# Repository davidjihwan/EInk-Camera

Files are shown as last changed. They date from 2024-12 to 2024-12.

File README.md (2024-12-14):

# eInk Camera
A camera that uses an eInk display, using the Adafruit Grand Central M4.
Image of the eink camera

## Summary
This project is an eInk camera. The camera takes a picture of the user when they click a button, saves it to an SD card, then flashes it onto an eInk display. 
More of the design details and process can be found in the writeup I did on [my website](https://davidjihwan.com/eInk-Camera).

## Media
Thresholding: <br />
Gif of the camera's thresholding function

Dithering (default): <br />
Gif of the camera's dithering function

The full interaction (dithering): <br />
Gif of the full camera interaction

Closeup: <br />
Gif of the full camera interaction

## Materials
- [Arduino IDE](https://www.arduino.cc/en/software)
- [Adafruit Grand Central M4 Express](http://www.adafruit.com/product/4064#tutorials)
- [Adafruit 1.54" Monochrome eInk / ePaper Display with SRAM](http://www.adafruit.com/product/4196#tutorials)
- [Adafruit EYESPI Breakout Board](http://www.adafruit.com/product/5613#tutorials)
- [EYESPI Cable - 18 Pin 100mm long Flex PCB (FPC) A-B type](https://www.adafruit.com/product/5239#tutorials)
- Micro USB cable (data)
- SD Card
- OV7670 Camera Module
- 2x: 2.2k resistors
- Breadboard
- M-F jumper wires
- M-M jumper wires
- Wires
- Pushbutton
  
Optional (for display enclosure):
- 2x: M2 screws & nuts

This project also requires soldering.

## Quick Start Guide
Download the [Arduino IDE](https://www.arduino.cc/en/software) on your computer of choice.

Camera setup:
1. Install the Adafruit OV7670 library using the Arduino Library Manager. 
2. Follow Phillip Burgess' guide "Adafruit OV7670 Camera Library For SAMD51 Processors" to modify the OV7670 camera to interface with the Grand Central: 
[https://learn.adafruit.com/adafruit-ov7670-camera-library-samd51/hardware](https://learn.adafruit.com/adafruit-ov7670-camera-library-samd51/hardware)  
Your camera should look like this after modification: <br />
<a href="url"> <br />
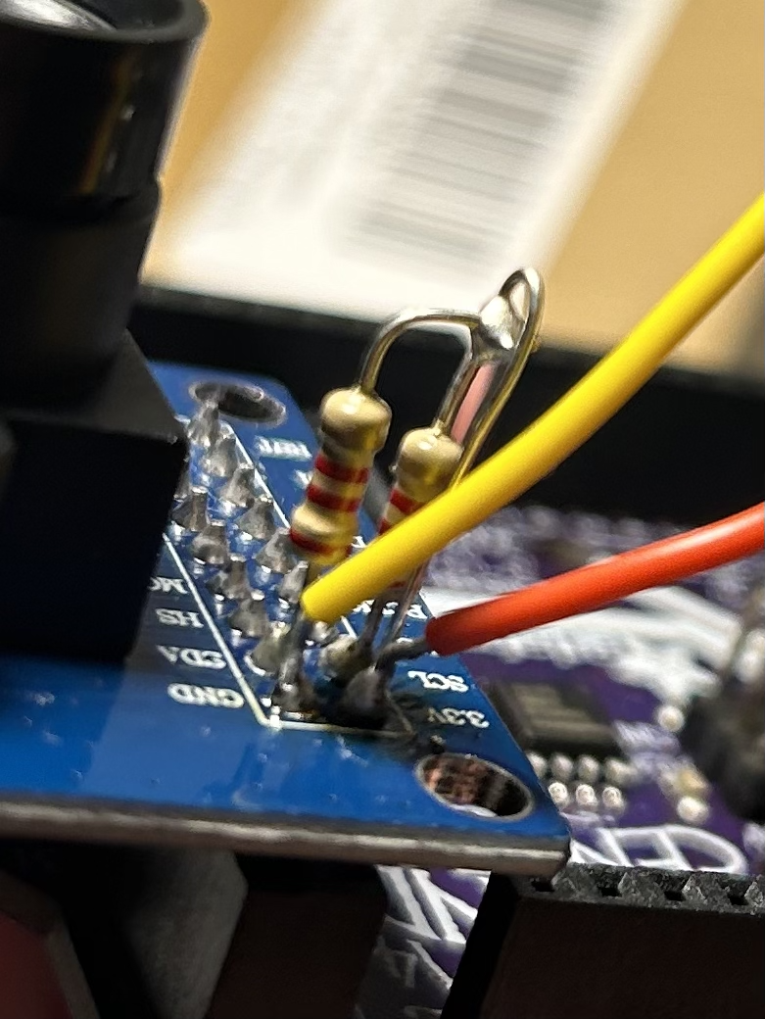
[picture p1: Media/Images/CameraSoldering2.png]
<a href="url"> <br />
Insert the camera into the Grand Central as detailed in the guide: <br />
<a href="url">
4. Ensure that the camera is working using the "selfie" example in the "Adafruit OV7670" library. You don't need the TFT screen; just remove the SD card and check the images manually. 

Eink setup:
1. Install the Adafruit EPD library using the Arduino Library Manager. 
2. Wire connections following the wiring diagram below.
3. Ensure that the eink display is working using the "ThinkInk_Mono" example in the "Adafruit EPD" library. If this isn't working, make sure to check that you are using a good data transfer micro USB cable. I ran into an issue where the subpar cable I used couldn't handle both the camera and eink display being plugged in at the same time.

Here's the wiring diagram for this project. <br />
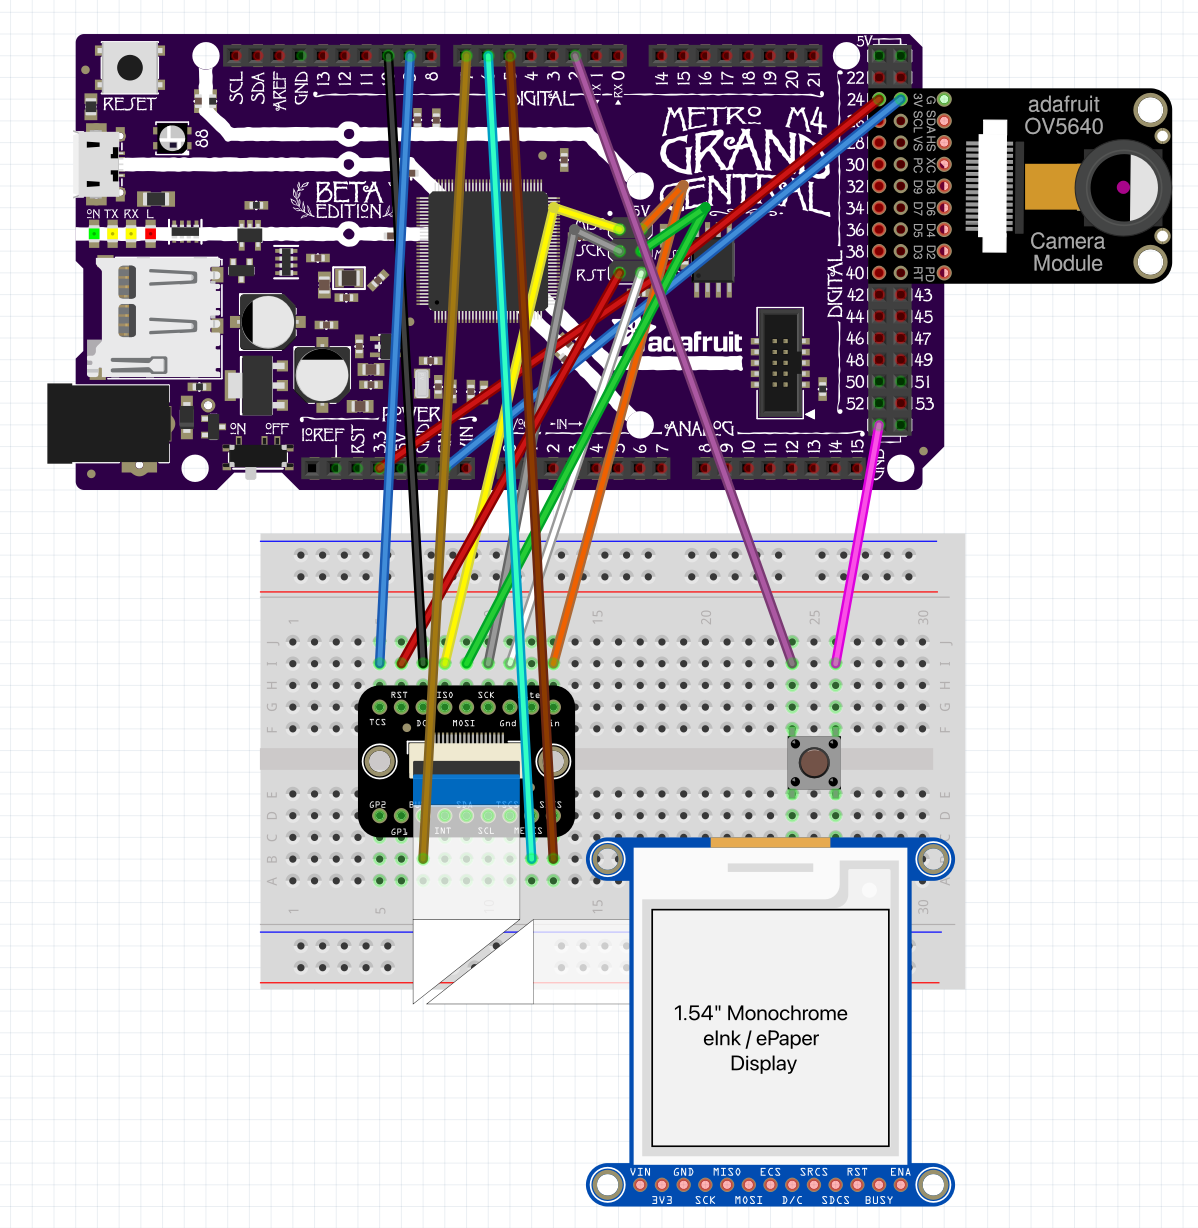
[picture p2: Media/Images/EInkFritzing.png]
<a href="url"> 

Here's what your wiring should look like:<br />
<a href="url"> <br />
<a href="url"> <br />

Project Installation and Setup:
1. Download the Arduino project file to write to serial output [here](Arduino/Eink_Camera/Eink_Camera.ino).
3. Open the project file.
4. Change your board: Tools > Boards > Adafruit SAMD Boards > Adafruit Grand Central M4
5. Change the port: Tools > Port > your-port (mac users should select “wchusb")
6. Plug the Grand Central into your computer.
7. Press the upload button (at the top left of the window) to upload your code to the board. Arduino should automatically download any missing dependencies. 
8. That's it! After you click the button, the image should be flashed onto the eink display. 

Optional Enclosure: <br />
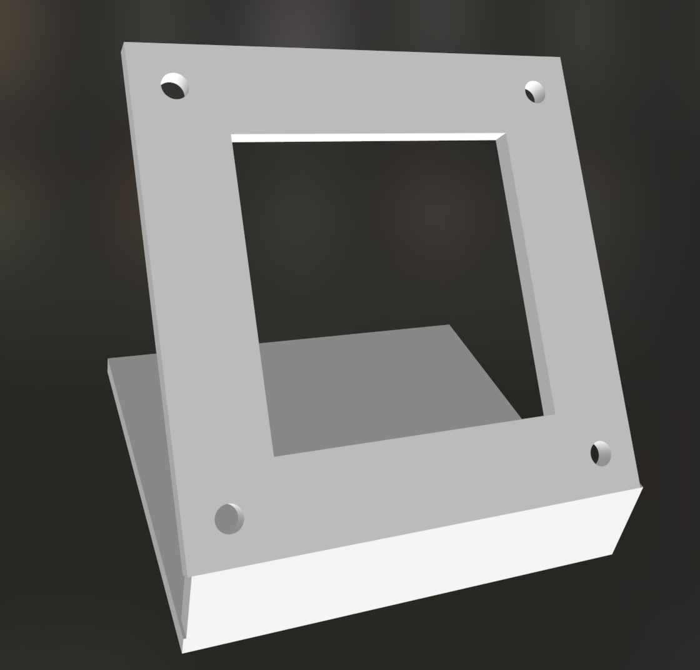
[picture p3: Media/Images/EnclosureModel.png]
<a href="url">
1. Download the file for the joystick enclosure [here](3D_Models/EInkStandScaled.stl) and print it.
2. Screw the eink display onto the back of the enclosure using M2 screws and hold it in place using the corresponding nuts.
The final enclosure looks like this: <br />
<a href="url">

I also tried making a cardboard enclosure for the camera: <br />
<a href="url">

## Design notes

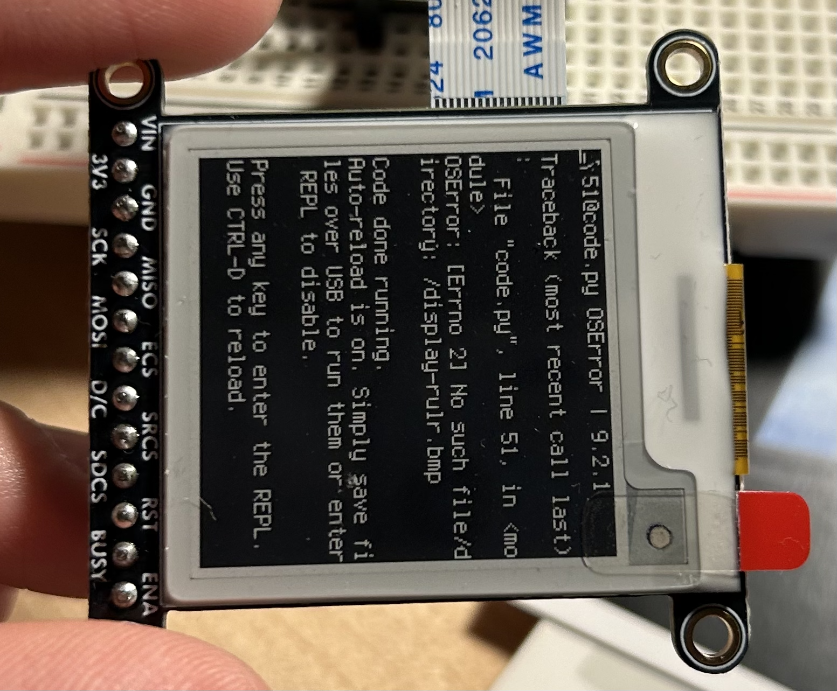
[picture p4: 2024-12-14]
Media/Images/EinkError.png

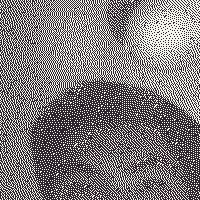
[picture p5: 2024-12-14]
Media/Images/dithered.png

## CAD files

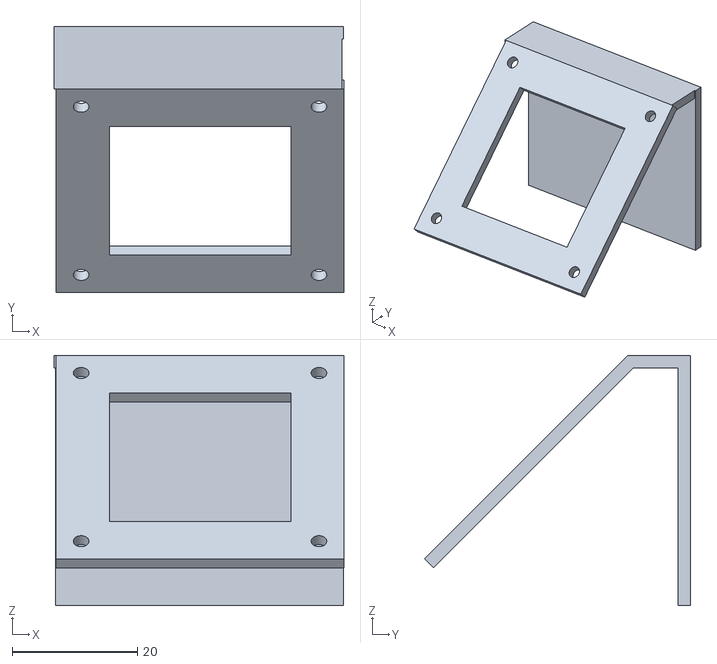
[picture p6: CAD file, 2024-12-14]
3D_Models/EInkStandScaled.stl
46.3 x 42.5 x 40.0

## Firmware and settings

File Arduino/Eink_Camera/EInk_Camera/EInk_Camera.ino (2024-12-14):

/*
Author: David Jihwan
Github: https://github.com/davidjihwan/eInk_Camera/tree/main
Website: https://davidjihwan.com/eInk-Camera

Takes a picture of the user when they click a button, saves it to an SD card, then flashes it onto an eInk display. 

HARDWARE REQUIRED:
- Adafruit Grand Central board
- OV7670 camera w/2.2K pullups to SDA+SCL
- Adafruit ThinkInk display
- SD Card

This project draws from example code written by Adafruit: 
- Examples/Adafruit ImageReader Library/ThinkInkDisplays: 
https://github.com/adafruit/Adafruit_ImageReader/blob/master/examples/ThinkInkDisplays/ThinkInkDisplays.ino
- Examples/Adafruit OV7670/selfie: 
https://github.com/adafruit/Adafruit_OV7670/blob/master/examples/selfie/selfie.ino

I also referenced Phillip Burgess' guide "Adafruit OV7670 Camera Library For SAMD51 Processors" 
in order to modify my OV7670 camera to interface with the Grand Central: 
https://learn.adafruit.com/adafruit-ov7670-camera-library-samd51/hardware  

*/

#include <Adafruit_GFX.h>             // Core graphics library
#include "Adafruit_ThinkInk.h"        // ThinkInk library
#include <Wire.h>                     // I2C comm to camera
#include "Adafruit_OV7670.h"          // Camera library
#include <SdFat.h>                    // SD card & FAT filesystem library
#include <Adafruit_SPIFlash.h>        // SPI / QSPI flash library
#include <Adafruit_ImageReader_EPD.h> // Image-reading functions

// SD CONFIG ----------------------------------------------------------
// #define SD_CS SDCARD_SS_PIN       // Grand Central onboard SD card select
#define SD_CS 5                      // SD card chip select (on ThinkInk Display)
SdFat                    SD;         // SD card filesystem
Adafruit_ImageReader_EPD reader(SD); // Image-reader object, pass in SD filesys

// CAMERA CONFIG -----------------------------------------------------------

// Set up arch and pins structures for Grand Central's SAMD51.
// PCC data pins are not configurable and do not need specifying.
OV7670_arch arch = {.timer = TCC1, .xclk_pdec = false};
OV7670_pins pins = {.enable = PIN_PCC_D8, .reset = PIN_PCC_D9,
                    .xclk = PIN_PCC_XCLK};
#define CAM_I2C  Wire1 // Second I2C bus next to PCC pins
#define CAM_SIZE OV7670_SIZE_DIV2 // QVGA (320x240 pixels)
#define CAM_MODE OV7670_COLOR_YUV // We need to process greyscale data
Adafruit_OV7670 cam(OV7670_ADDR, &pins, &CAM_I2C, &arch);

// EINK DISPLAY CONFIG -----------------------------------------------------------
#define EPD_DC      10
#define EPD_CS      9
#define EPD_BUSY    7    // can set to -1 to not use a pin (will wait a fixed delay)
#define SRAM_CS     6
#define EPD_RESET   -1   // can set to -1 and share with microcontroller Reset!
#define EPD_SPI     &SPI // primary SPI
// 1.54" Monochrome displays with 200x200 pixels and SSD1681 chipset
// ThinkInk_154_Mono_D67 display(EPD_DC, EPD_RESET, EPD_CS, SRAM_CS, EPD_BUSY, EPD_SPI);
ThinkInk_154_Mono_D67 display(EPD_DC, EPD_RESET, EPD_CS, SRAM_CS, EPD_BUSY);

// BUTTON CONFIG -----------------------------------------------------------
#define BUTTON_PIN 2

// SETUP - RUNS ONCE ON STARTUP --------------------------------------------
void setup() {
  pinMode(13, OUTPUT);  // Onboard red LED
  pinMode(BUTTON_PIN, INPUT_PULLUP); // Use internal pullup resistor
  Serial.begin(9600);
  Serial.println("Began!");

  // Initialize SD & file system
  if(!SD.begin(SD_CS, SD_SCK_MHZ(10))) { // Breakouts require 10 MHz limit due to longer wires
    Serial.println(F("SD begin() failed"));
    for(;;); // Fatal error, do not continue
  }

  // Once started, the camera continually fills a frame buffer using DMA.
  OV7670_status status = cam.begin(CAM_MODE, CAM_SIZE, 30.0, 320 * 240 * 2);
  if (status != OV7670_STATUS_OK) {
    Serial.println("Camera begin() fail");
    for(;;); // Fatal error, do not continue
  }
  // We don't want DMA into the camera buffer for this project, as
  // the camera should only be active when the button is pressed.
  cam.suspend();
  display.begin();
  display.setRotation(2);
  display.clearBuffer();
}

// MAIN LOOP - RUNS REPEATEDLY UNTIL RESET OR POWER OFF --------------------
void loop() {
  delay(40);  // Check button press every 40ms
  int buttonState = digitalRead(BUTTON_PIN);
  if(!buttonState) {
    digitalWrite(13, HIGH);   // turn the LED on

    // ********** HANDLE CAMERA **********
    Serial.println("Taking picture.");
    char filename[50];
    sprintf(filename, "selfie.bmp");
    // delay(500);      // Small delay for user to get ready
    cam.capture();      // Manual (non-DMA) capture
    bool *correspondence = (bool *)malloc(cam.height() * cam.width() * sizeof(bool));   // Remember to free!!!
    if (correspondence == NULL) {
      Serial.println("Correspondence malloc error");
      for(;;); // Fatal error, do not continue
    }
    dither(cam.getBuffer(), cam.width(), cam.height(), correspondence);
    write_bmp_correspond(filename, correspondence, cam.width(), cam.height(), 
                       display.height(), display.width());
    free(correspondence);

    // ********** HANDLE SCREEN **********
    // Load full-screen BMP file 'selfie.bmp' at position (0,0) (top left).
    // The 'reader' object performs this, with 'epd' as an argument.
    Serial.print(F("Loading bmp to canvas..."));
    ImageReturnCode stat; // Status from image-reading functions
    stat = reader.drawBMP((char *)"selfie.bmp", display, 0, 0);
    reader.printStatus(stat); // How'd we do?
    display.display();  
    display.clearBuffer();
    digitalWrite(13, LOW);  // Turn the LED off
    delay(5000);            // Adafruit recommends a max refresh rate of 180 seconds. If you care
                            // about the longevity of your screen, increase the delay. 
  }
}

// Perform Floyd-Steinberg dithering on the image and fill in the correspondence array with the 
// results (0: black, 1: white). 
// This changes the values in the camera buffer in order to avoid using more RAM. Use with caution.
void dither(uint16_t *addr, uint16_t width, uint16_t height, bool *correspondence){
  // Serial.println("Dithering.");
  if(CAM_MODE != OV7670_COLOR_YUV) {
    Serial.println("Camera mode not YUV (continuing)!");
  }
  // Floyd-Steinberg dithering
  // https://en.wikipedia.org/wiki/Floyd%E2%80%93Steinberg_dithering
  for(int y=0; y<height; y++) {
    uint16_t *row = &addr[y * width];
    // uint8_t *row = &addr[y * width];
    for(int x=0;x <width; x++) { 
      // The low-byte of YUV pixels holds the brightness information.
      // Raw data from camera is big-endian, so the second byte will hold brightness.
      uint16_t be_pixel = row[x];
      uint8_t old_pixel = be_pixel & 0xFF;  // brightness
      // uint8_t brightness = (le_pixel >> 8) & 0xFF;
      int dither_thresh = 128;
      uint8_t new_pixel = (old_pixel >= dither_thresh) ? 255 : 0;
      correspondence[y*width + x] = new_pixel == 0 ? 1 : 0; 
      uint8_t quant_error = old_pixel - new_pixel;
      bool xl = true;
      bool xr = true;
      bool yr = true;
      // Check bounds
      if (y==height-1){
        yr = false;
      }
      if (x==0){
        xl = false;
      }
      if (x==width-1){
        xr = false;
      }
      if (xr){
        uint16_t neighbor_pixel = row[x+1];
        uint8_t diffuse_pixel = neighbor_pixel & 0xFF;
        diffuse_pixel += quant_error * (7.0/16.0);
        uint8_t high_byte = (neighbor_pixel >> 8) & 0xFF;
        row[x+1] = (high_byte << 8) | diffuse_pixel;
      }
      if (yr){
        uint16_t *nrow = &addr[(y+1) * width];
        if (xl){
          uint16_t neighbor_pixel = nrow[x-1];
          uint8_t diffuse_pixel = neighbor_pixel & 0xFF;
          diffuse_pixel += quant_error * (3.0/16.0);
          uint8_t high_byte = (neighbor_pixel >> 8) & 0xFF;
          nrow[x-1] = (high_byte << 8) | diffuse_pixel;
        }
        if (xr){
          uint16_t neighbor_pixel = nrow[x+1];
          uint8_t diffuse_pixel = neighbor_pixel & 0xFF;
          diffuse_pixel += quant_error * (1.0/16.0);
          uint8_t high_byte = (neighbor_pixel >> 8) & 0xFF;
          nrow[x+1] = (high_byte << 8) | diffuse_pixel;
        }
        uint16_t neighbor_pixel = nrow[x];
        uint8_t diffuse_pixel = neighbor_pixel & 0xFF;
        diffuse_pixel += quant_error * (5.0/16.0);
        uint8_t high_byte = (neighbor_pixel >> 8) & 0xFF;
        nrow[x] = (high_byte << 8) | diffuse_pixel;
      }
    }
  }
  Serial.println("Dithering done.");
}

// Threshold the image and fill in the correspondence array with the 
// results (0: black, 1: white). 
void threshold(uint16_t *addr, uint16_t width, uint16_t height, bool *correspondence){
  int thresh = 90;
  if(CAM_MODE != OV7670_COLOR_YUV) {
    Serial.println("Camera mode not YUV!");
    for(;;); // Fatal error, do not continue
  }
  for(int y=0; y<height; y++) {
    uint16_t *row = &addr[y * width];
    for(int x=0;x <width; x++) { 
      // The low-byte of YUV pixels holds the brightness information.
      // Raw data from camera is big-endian, so the second byte will hold brightness.
      uint16_t be_pixel = row[x];
      // uint8_t brightness = (le_pixel >> 8) & 0xFF;
      uint8_t brightness = be_pixel & 0xFF;
      bool res = 0;
      if (brightness >= thresh){
        res = 1;
      } 
      correspondence[y*width + x] = res;
    }
  }
  Serial.println("Thresholding done.");
}

// Write 16-bit value to BMP file in little-endian order
void writeLE16(File *file, uint16_t value) {
#if(__BYTE_ORDER__ == __ORDER_LITTLE_ENDIAN__)
  file->write((char *)&value, sizeof value);
#else
  file->write( value       & 0xFF);
  file->write((value >> 8) & 0xFF);
#endif
}

// Write 32-bit value to BMP file in little-endian order
void writeLE32(File *file, uint32_t value) {
#if(__BYTE_ORDER__ == __ORDER_LITTLE_ENDIAN__)
  file->write((char *)&value, sizeof value);
#else
  file->write( value        & 0xFF);
  file->write((value >>  8) & 0xFF);
  file->write((value >> 16) & 0xFF);
  file->write((value >> 24) & 0xFF);
#endif
}

// Dithered array to 24 bit BMP-writing function.
// This also crops the original array to dis_width, dis_height.
// BMP file format: https://en.wikipedia.org/wiki/BMP_file_format
void write_bmp_correspond(char *filename, bool *correspondence, uint16_t width, uint16_t height,
                        uint16_t dis_width, uint16_t dis_height) {
  SD.remove(filename); // Delete existing file, if any
  File file = SD.open(filename, FILE_WRITE);
  if(file) {
    // BMP header, 14 bytes:
    file.write(0x42);                               // Windows BMP signature
    file.write(0x4D);                               // "
    writeLE32(&file, 14 + 56 + dis_width * dis_height * 3); // File size in bytes
    writeLE32(&file, 0);                            // Creator bytes (ignored)
    writeLE32(&file, 14 + 56);                      // Offset to pixel data
  
    // DIB header, 56 bytes "BITMAPV3INFOHEADER" type (for RGB565):
    writeLE32(&file, 56);                     // Header size in bytes
    writeLE32(&file, dis_width);              // Width in pixels
    writeLE32(&file, dis_height);             // Height in pixels (bottom-to-top)
    writeLE16(&file, 1);                      // Planes = 1
    writeLE16(&file, 24);                     // Bits = 24
    // writeLE32(&file, 3);                   // Compression = bitfields
    writeLE32(&file, 0);                      // Compression = bitfields
    writeLE32(&file, dis_width * dis_height); // Bitmap size (adobe adds 2 here also)
    writeLE32(&file, 2835);                   // Horiz resolution (72dpi)
    writeLE32(&file, 2835);                   // Vert resolution (72dpi)
    writeLE32(&file, 0);                      // Default # colors in palette
    writeLE32(&file, 0);                      // Default # "important" colors
    writeLE32(&file, 0b1111100000000000);     // Red mask
    writeLE32(&file, 0b0000011111100000);     // Green mask
    writeLE32(&file, 0b0000000000011111);     // Blue mask
    writeLE32(&file, 0);                      // Alpha mask

    // Colors vals from https://learn.adafruit.com/preparing-graphics-for-e-ink-displays/command-line
    uint32_t white = 0xf4f4ec;
    uint32_t black = 0x2c242c;

    if (dis_width > width || dis_height > height){
      Serial.println("Cropped image exceed original dimensions!");
      dis_width = width;
      dis_height = height;
    }
    int x_buf = floor((width-dis_width)/2);
    int y_buf = floor((height-dis_height)/2);
    for(int y=0; y<dis_height; y++) {
      for(int x=dis_width-1;x >= 0; x--) { // Flip X
        uint32_t pixel = black;
        if (correspondence[(y+y_buf)*width + (x+x_buf)] == true){
          pixel = white;
        }
        file.write((char *)&pixel, 3);
      }
      // No scanline pad is added. We know the OV7670 library image sizes
      // are always an even width (4 bytes). Something to keep in mind if
      // flexible sizing and/or cropping options are added later.
    }
    file.close();
    Serial.println("Writing dithered BMP done.");
  }
}


// // Cropping is centered.
// void crop_img(uint16_t *addr, uint16_t *cropped_img, uint16_t width, uint16_t height, 
//                   uint16_t crop_width, uint16_t crop_height){
//   if (crop_width > width || crop_height > height){
//     Serial.println("Cropped image exceed original dimensions.");
//     return;
//   } 
//   int width_buf = floor((width-crop_width)/2);
//   int height_buf = floor((height-crop_height)/2);
  
//   for(int y=0; y<crop_height; ++y) {
//     uint16_t *row = &addr[(y + height_buf) * width];
//     for(int x=0;x <crop_width; ++x) { 
//       uint16_t pixel = row[x + width_buf];
//       cropped_img[y * crop_width + x] = pixel;
//     }
//   }
//   Serial.println("Done cropping.");
// }

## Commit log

2024-12-13 Arduino Code
2024-12-14 New media
    [EInkStandScaled.stl]
